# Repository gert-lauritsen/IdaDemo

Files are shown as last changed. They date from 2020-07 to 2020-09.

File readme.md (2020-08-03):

# Homeautomation fra pcb til produkt

## Beskrivelse

Vi vil forsøg på en aften at gå fra en ide til et produkt/prototype. Til formålet vil vi bruge Kicad, som vil blive gennemgået. Sende det til produktion monterer det og hælde kode i den. Til sidst vil vi lige se på WFF i homeautomation. Vi skal bl.a. se på dørlåse, automatiske gardiner og Automatisk lys.

* Kode på esp8266/esp32 i arduino IDE
* Udlægning af print med KIcad
* Mqtt og hvordan vi kan bruge det i automation
* Samarbejde via GitHUB

Niveauet bliver let så alle der har lyst til at prøve at udvikle deres egen print eller automatik, vil få en god start på deres produkt. Dette er for begynder, så bare kom og vær med.

Redskab bærbar med følgende installeret:
* [KiCad](https://kicad-pcb.org/download/)
* [Arduino](https://www.arduino.cc/)

Plan

* snakke om hvorfor og hvorfor ikke automation er smart
* Kicad gennemgang
* Kodning i arduino
* Samarbejde og deling via github

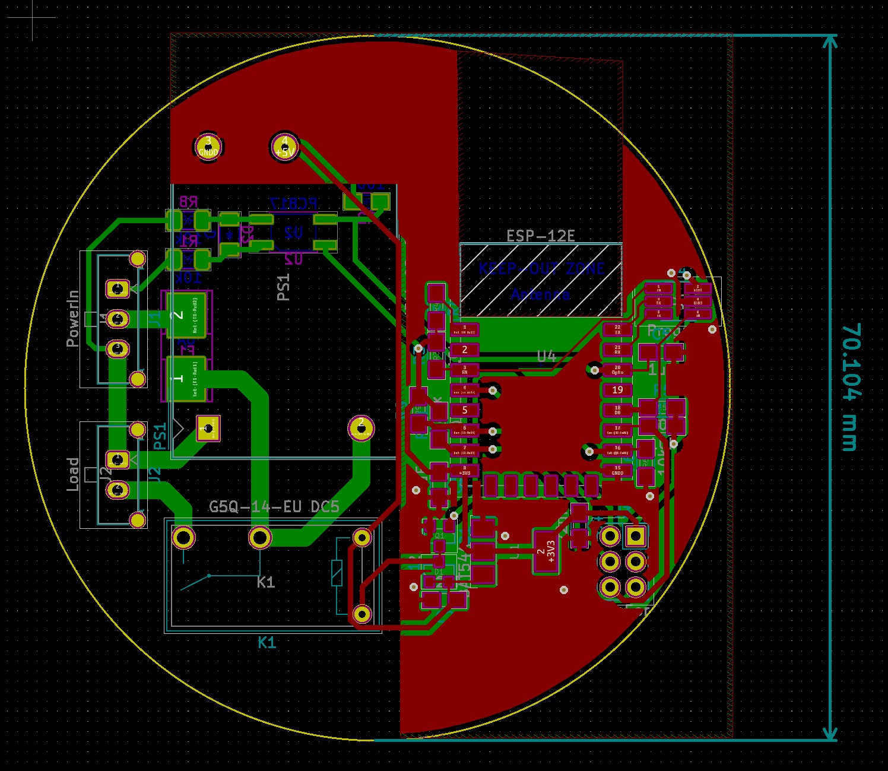
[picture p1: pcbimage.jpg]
Print


##Install ESP8266 på arduino
Under preference sætte følgede linie ind i additional boards:
https://dl.espressif.com/dl/package_esp32_index.json, http://arduino.esp8266.com/stable/package_esp8266com_index.json

Gå til Tools>Board>BoardManager søg efter esp8266 tryk install

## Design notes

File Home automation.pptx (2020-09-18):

## Home automation

Fra ide over pcb til prototype

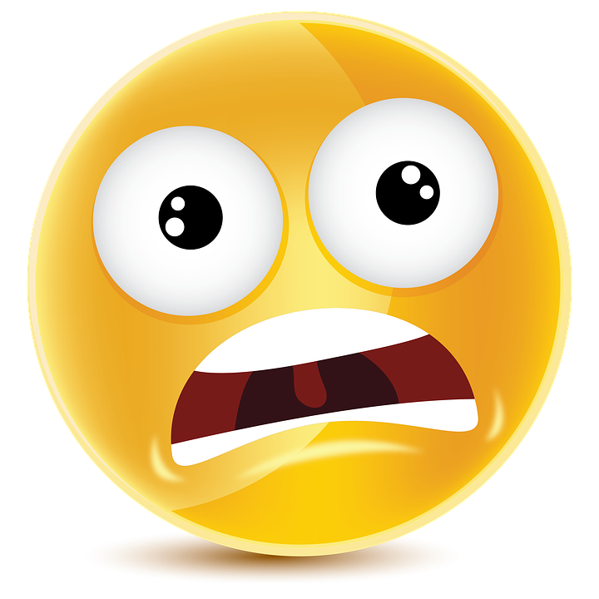
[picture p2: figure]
Smiley, Emoji, Følelser, Humørikon, Ansigt, Tegneserie

## Velkommen

- Esp8266 / Esp8265 / Esp32
- Wifi
- BootLoader
- Lysstyring (hvad Philips hue ikke kan)

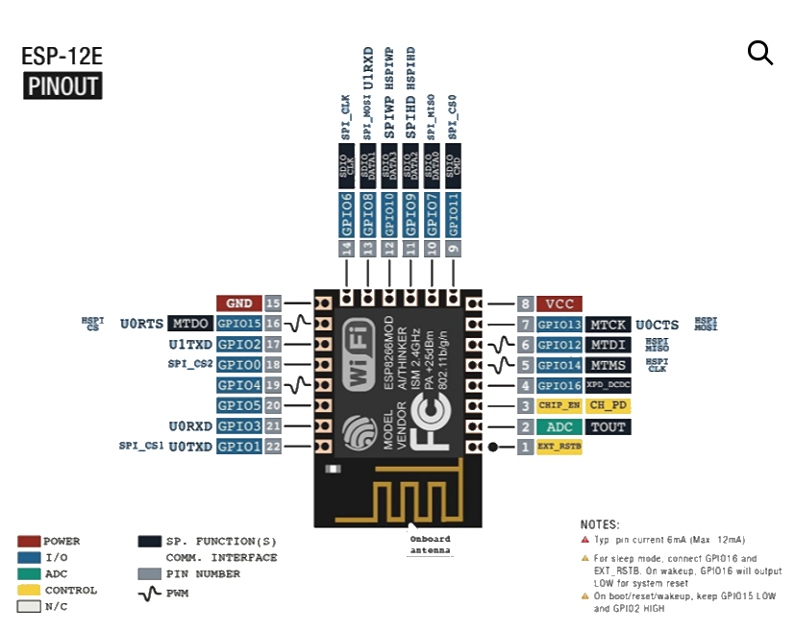
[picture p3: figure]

## Kicad

- Schematic (place, hieraki,
- SamacSys
- PCB
- Produktion

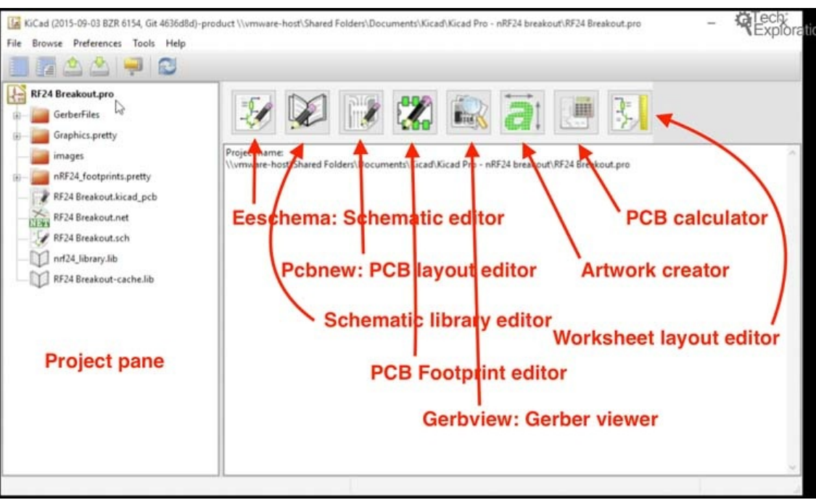
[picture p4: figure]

## GitHub

- Hvad er GIT
- Branches
- Samarbejde

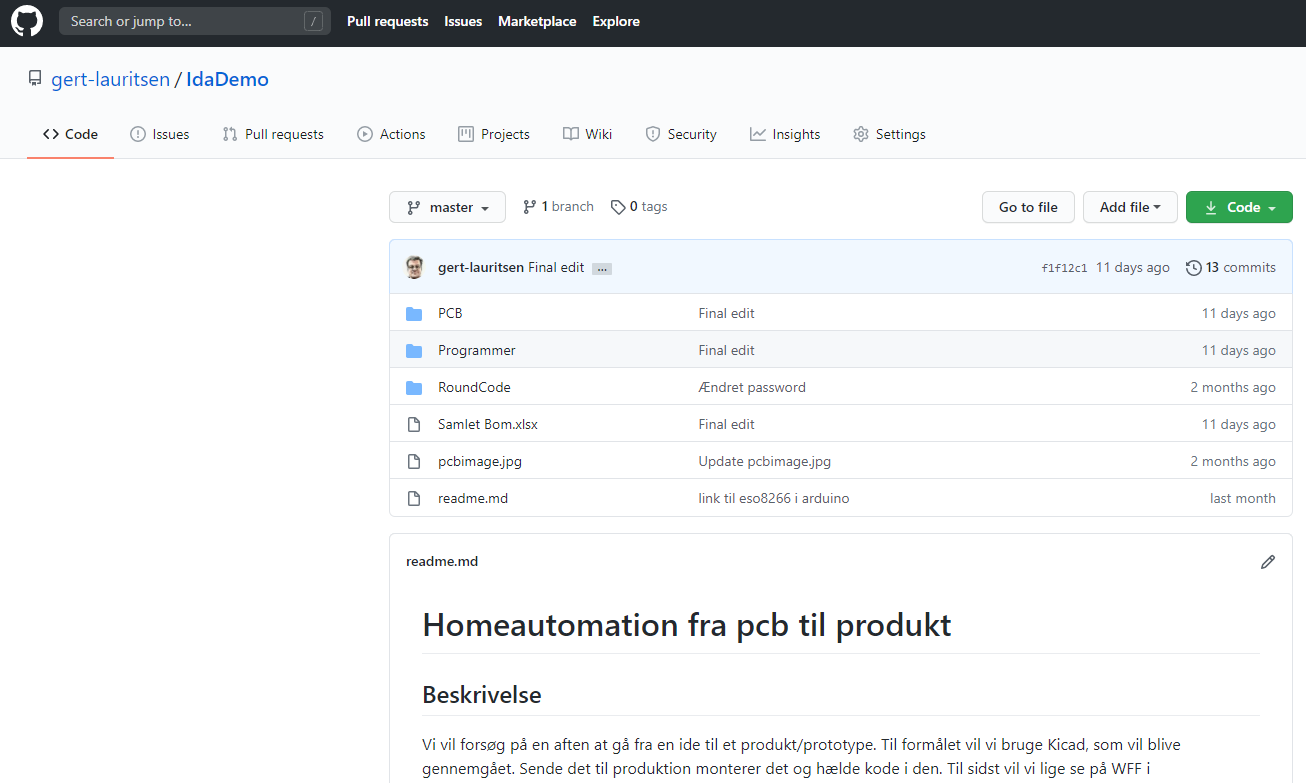
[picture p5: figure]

## MQTT

- Historik
- Pub/sub
- Frames, Topic, Json

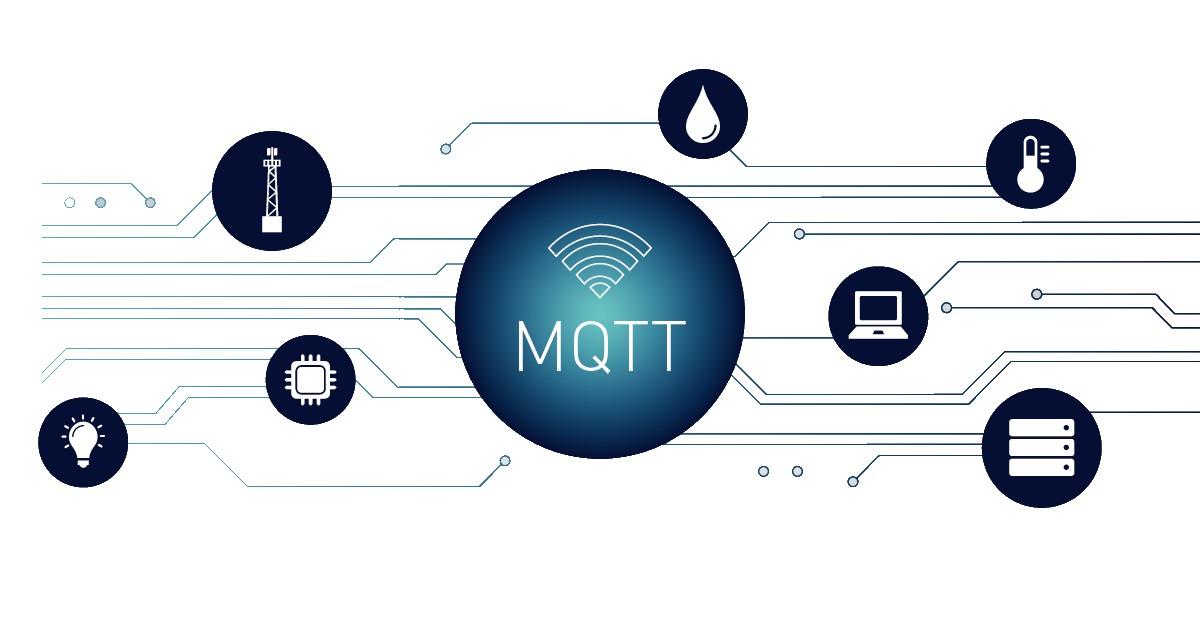
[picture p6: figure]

## OpenhaB

- Items
- Sitemap
- Rules

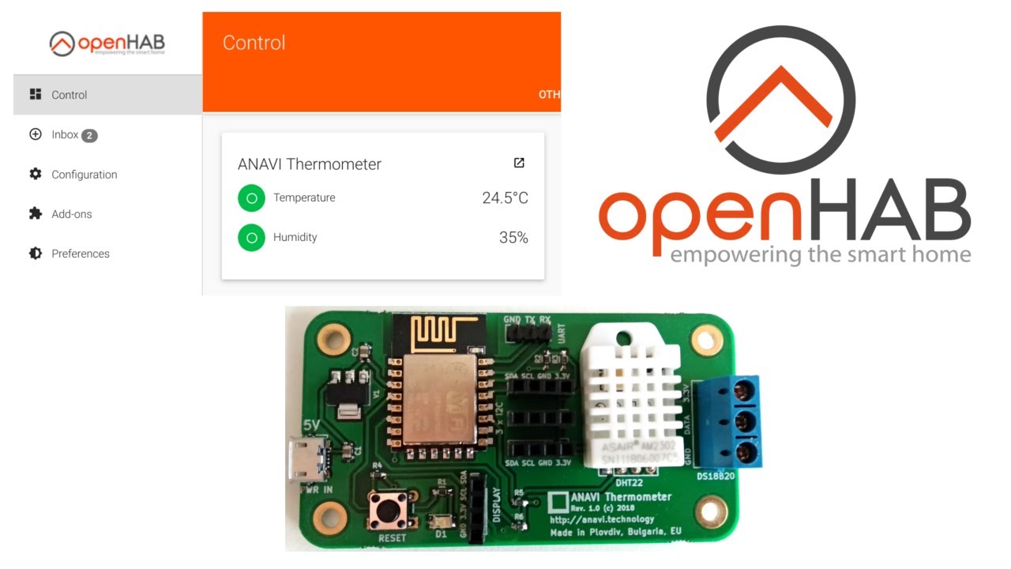
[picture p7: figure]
Connecting Temperature and Humidity Sensor DHT22 to OpenHAB 2 with MQTT - YouTube

## Arduino

- Install
- Libery
- Homeautomation “hallo world”

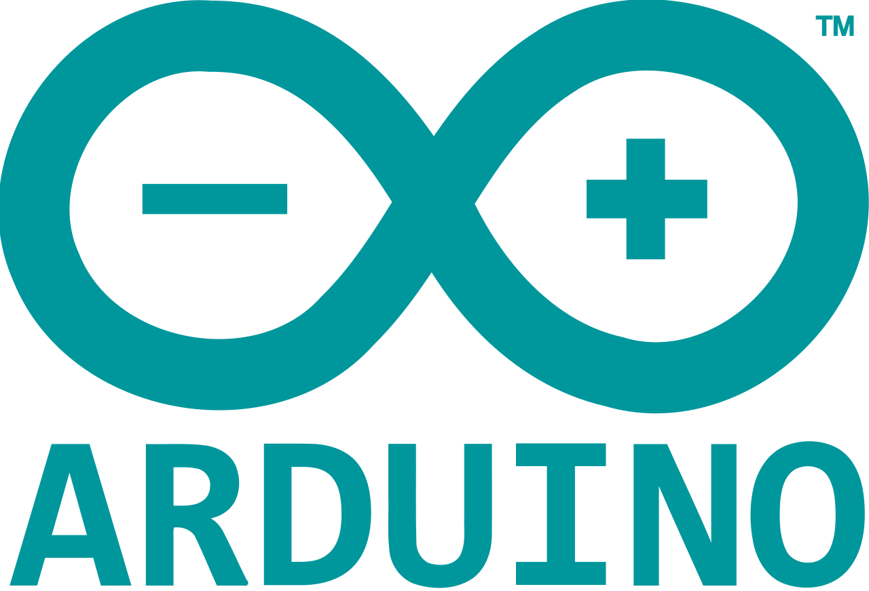
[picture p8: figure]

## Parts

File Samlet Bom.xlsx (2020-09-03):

U2 | FT232RL-REEL | Package_SO:SSOP-28_5.3x10.2mm_P0.65mm | https://www.ftdichip.com/Support/Documents/DataSheets/ICs/DS_FT232R.pdf | Active | Status | dk_Interface-Controllers | FT232RL-REEL | IC USB FS SERIAL UART 28-SSOP
J2 | Prog | Connector_PinHeader_1.27mm:PinHeader_2x03_P1.27mm_Vertical_SMD | ~ |  |  | Connector_Generic | Conn_02x03_Odd_Even | Generic connector, double row, 02x03, odd/even pin numbering scheme (row 1 odd numbers, row 2 even numbers), script generated (kicad-library-utils/schlib/autogen/connector/)
C4 | 100nF | Capacitor_SMD:C_0805_2012Metric | ~ |  |  | Device | C_Small | Unpolarized capacitor, small symbol
Q1 | BC846BS | Package_TO_SOT_SMD:SOT-363_SC-70-6 | https://assets.nexperia.com/documents/data-sheet/BC846BS.pdf |  |  | Transistor_BJT | BC846BS | 100mA IC, 65V Vce, Dual NPN/NPN Transistors, SOT-363
R5 | 10k | Resistor_SMD:R_0805_2012Metric | ~ |  |  | Device | R_Small | Resistor, small symbol
R6 | 10k | Resistor_SMD:R_0805_2012Metric | ~ |  |  | Device | R_Small | Resistor, small symbol
U1 | AP2112K-3.3 | Package_TO_SOT_SMD:SOT-23-5 | https://www.diodes.com/assets/Datasheets/AP2112.pdf |  |  | Regulator_Linear | AP2112K-3.3 | 600mA low dropout linear regulator, with enable pin, 3.8V-6V input voltage range, 3.3V fixed positive output, SOT-23-5
C2 | 1uF | Capacitor_SMD:C_0805_2012Metric | ~ |  |  | Device | C_Small | Unpolarized capacitor, small symbol
C3 | 1uF | Capacitor_SMD:C_0805_2012Metric | ~ |  |  | Device | C_Small | Unpolarized capacitor, small symbol
FB1 | Ferrite Bead | Inductor_SMD:L_0805_2012Metric | ~ |  |  | Device | Ferrite_Bead_Small | Ferrite bead, small symbol
C1 | 10nF | Capacitor_SMD:C_0805_2012Metric | ~ |  |  | Device | C_Small | Unpolarized capacitor, small symbol
D2 | LED | LED_SMD:LED_0805_2012Metric | ~ |  |  | Device | LED | Light emitting diode
D3 | LED | LED_SMD:LED_0805_2012Metric | ~ |  |  | Device | LED | Light emitting diode
R7 | 1k | Resistor_SMD:R_0805_2012Metric | ~ |  |  | Device | R_Small | Resistor, small symbol
R8 | 1k | Resistor_SMD:R_0805_2012Metric | ~ |  |  | Device | R_Small | Resistor, small symbol
SW1 | SW_Push | Button_Switch_SMD:SW_Push_1P1T_NO_6x6mm_H9.5mm | ~ |  |  | Switch | SW_Push | Push button switch, generic, two pins
SW2 | SW_Push | Button_Switch_SMD:SW_Push_1P1T_NO_6x6mm_H9.5mm | ~ |  |  | Switch | SW_Push | Push button switch, generic, two pins
J3 | USB_A | Connector_USB:USB_Mini-B_Wuerth_65100516121_Horizontal | ~ |  |  | Connector | USB_A | USB Type A connector
D1 | 82400102 | SOT95P280X145-6N | http://katalog.we-online.de/pbs/datasheet/82400102.pdf | 82400102 | Arrow Part Number | Programmer-rescue | 82400102-SamacSys_Parts
U2 | LTV-355T | Housings_SOIC:SO-4_4.4x3.6mm_Pitch2.54mm | https://www.mouser.dk/datasheet/2/239/LTV-355T%20Series-1308-1175436.pdf |  |  | Isolator | LTV-355T | Transistor Output Optocouplers Optocoupler Photodarlington
R1 | 33K | Resistor_SMD:R_1206_3216Metric | ~ |  |  | Device | R_Small | Resistor, small symbol
J1 | PowerIn | Connector_Molex:Molex_Micro-Fit_3.0_43650-0315_1x03_P3.00mm_Vertical | ~ |  |  | Connector_Generic | Conn_01x03 | Generic connector, single row, 01x03, script generated (kicad-library-utils/schlib/autogen/connector/)
J2 | Load | Connector_Molex:Molex_Micro-Fit_3.0_43650-0215_1x02_P3.00mm_Vertical | ~ |  |  | Connector_Generic | Conn_01x02 | Generic connector, single row, 01x02, script generated (kicad-library-utils/schlib/autogen/connector/)
U4 | ESP-12E | RF_Module:ESP-12E | http://wiki.ai-thinker.com/_media/esp8266/esp8266_series_modules_user_manual_v1.1.pdf |  |  | RF_Module | ESP-12E | 802.11 b/g/n Wi-Fi Module
R4 | 10k | Resistors_SMD:R_0805_HandSoldering | ~ |  |  | Device | R_Small | Resistor, small symbol
R3 | 10k | Resistors_SMD:R_0805_HandSoldering | ~ |  |  | Device | R_Small | Resistor, small symbol
R5 | 10k | Resistors_SMD:R_0805_HandSoldering | ~ |  |  | Device | R_Small | Resistor, small symbol
R6 | 10k | Resistors_SMD:R_0805_HandSoldering | ~ |  |  | Device | R_Small | Resistor, small symbol
R7 | 10k | Resistors_SMD:R_0805_HandSoldering | ~ |  |  | Device | R_Small | Resistor, small symbol
R2 | 100k | Resistors_SMD:R_0805_HandSoldering | ~ |  |  | Device | R_Small | Resistor, small symbol
Q1 | Sq2318AES | TO_SOT_Packages_SMD:SOT-23 | https://www.fairchildsemi.com/datasheets/2N/2N7002.pdf |  |  | Transistor_FET | 2N7002 | 0.115A Id, 60V Vds, N-Channel MOSFET, SOT-23
C2 | 1uF | Capacitors_SMD:C_0805_HandSoldering | ~ |  |  | Device | C_Small | Unpolarized capacitor, small symbol
C3 | 1uF | Capacitors_SMD:C_0805_HandSoldering | ~ |  |  | Device | C_Small | Unpolarized capacitor, small symbol
C4 | 1uF | Capacitors_SMD:C_0805_HandSoldering | ~ |  |  | Device | C_Small | Unpolarized capacitor, small symbol
D2 | D | Diodes_SMD:D_1206 | ~ |  |  | Device | D | Diode
K1 | G5Q-14-EU DC5 | Relay_THT:Relay_SPST_Omron-G5Q-1A | https://www.omron.com/ecb/products/pdf/en-g5q.pdf |  |  | Relay | G5Q-1A | Omron G5Q relay, Miniature Single Pole, SPST-NO, 10A
C5 | 1uF | Capacitors_SMD:C_0805_HandSoldering | ~ |  |  | Device | C_Small | Unpolarized capacitor, small symbol
PS1 | IRM-02-5 | Converter_ACDC:Converter_ACDC_MeanWell_IRM-02-xx_THT | http://www.meanwell.com/productPdf.aspx?i=675 |  |  | loftrelayRound-rescue | IRM-02-5-Converter_ACDC
J4 | Program | Pin_Headers:Pin_Header_Straight_2x03_Pitch1.27mm_SMD | ~ |  |  | Connector_Generic | Conn_02x03_Odd_Even | Generic connector, double row, 02x03, odd/even pin numbering scheme (row 1 odd numbers, row 2 even numbers), script generated (kicad-library-utils/schlib/autogen/connector/)
D1 | BAT54A | Package_TO_SOT_SMD:SOT-23 | http://www.diodes.com/_files/datasheets/ds11005.pdf |  |  | Diode | BAT54A | schottky barrier diode
F1 | 8A | SMD_Packages:Fuse_SMD | ~ |  |  | Device | Fuse | Fuse
J3 | SenSor | Socket_Strips:Socket_Strip_Straight_2x03_Pitch2.54mm | ~ |  |  | Connector_Generic | Conn_02x03_Counter_Clockwise | Generic connector, double row, 02x03, counter clockwise pin numbering scheme (similar to DIP packge numbering), script generated (kicad-library-utils/schlib/autogen/connector/)
R9 | 10k | Resistors_SMD:R_0805_HandSoldering | ~ |  |  | Device | R_Small | Resistor, small symbol
R10 | 10k | Resistors_SMD:R_0805_HandSoldering | ~ |  |  | Device | R_Small | Resistor, small symbol
R8 | 100k/400V/0,25W | Resistor_SMD:R_1206_3216Metric | ~ |  |  | Device | R_Small | Resistor, small symbol
U1 | AP2112K-3.3 | Package_TO_SOT_SMD:SOT-23-5 | https://www.diodes.com/assets/Datasheets/AP2112.pdf |  |  | Regulator_Linear | AP2112K-3.3 | 600mA low dropout linear regulator, with enable pin, 3.8V-6V input voltage range, 3.3V fixed positive output, SOT-23-5

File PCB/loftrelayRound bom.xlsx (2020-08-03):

Source: | C:\ArbejdsFile\Askob\IDA\IdaDemo\PCB\loftrelayRound.sch
Date: | 2020-03-08 10:44
Tool: | Eeschema (5.1.5)-3
Generator: | C:\Program Files\KiCad\bin\scripting\plugins/bom_csv_grouped_by_value_with_fp.py
Component Count: | 27
Ref | Qnty | Value | Cmp name | Footprint | Description | Vendor
C2,C3,C4 | 3 | 22uF | C_Small | Capacitors_SMD:C_0805_HandSoldering | Unpolarized capacitor, small symbol
C5 | 1 | 1uF | C_Small | Capacitors_SMD:C_0805_HandSoldering | Unpolarized capacitor, small symbol
D1 | 1 | BAT54A | BAT54A | Package_TO_SOT_SMD:SOT-23 | schottky barrier diode
D2 | 1 | SD1206S020S1R0 | SD1206S020S1R0 | Diodes_SMD:D_1206 | Diode
F1 | 1 | 8A | Fuse | SMD_Packages:Fuse_SMD | Fuse
J1 | 1 | PowerIn | Conn_01x03 | Connector_Molex:Molex_Micro-Fit_3.0_43650-0315_1x03_P3.00mm_Vertical | Generic connector, single row, 01x03, script generated (kicad-library-utils/schlib/autogen/connector/)
J2 | 1 | Load | Conn_01x02 | Connector_Molex:Molex_Micro-Fit_3.0_43650-0215_1x02_P3.00mm_Vertical | Generic connector, single row, 01x02, script generated (kicad-library-utils/schlib/autogen/connector/)
J3 | 1 | SenSor | Conn_02x03_Counter_Clockwise | Socket_Strips:Socket_Strip_Straight_2x03_Pitch2.54mm | Generic connector, double row, 02x03, counter clockwise pin numbering scheme (similar to DIP packge numbering), script generated (kicad-library-utils/schlib/autogen/connector/)
J4 | 1 | Program | Conn_02x03_Odd_Even | Pin_Headers:Pin_Header_Straight_2x03_Pitch1.27mm_SMD | Generic connector, double row, 02x03, odd/even pin numbering scheme (row 1 odd numbers, row 2 even numbers), script generated (kicad-library-utils/schlib/autogen/connector/)
K1 | 1 | G5Q-14-EU DC5 | G5Q-1A | Relays_THT:Relay_SPST_OMRON-G5Q | Omron G5Q relay, Miniature Single Pole, SPST-NO, 10A
PS1 | 1 | IRM-02-5 | IRM-02-5-Converter_ACDC | Converter_ACDC:Converter_ACDC_MeanWell_IRM-02-xx_THT
Q1 | 1 | Sq2318AES | Sq2318AES | TO_SOT_Packages_SMD:SOT-23 | 0.115A Id, 60V Vds, N-Channel MOSFET, SOT-23
R1,R8 | 2 | 33k | R_Small !!300V | Resistor_SMD:R_1206_3216Metric / Rated til 300V | Resistor, small symbol
R2 | 1 | 100k | R_Small | Resistors_SMD:R_0805_HandSoldering | Resistor, small symbol
R3,R4,R5,R6,R7,R9,R10 | 7 | 10k | R_Small | Resistors_SMD:R_0805_HandSoldering | Resistor, small symbol
U1 | 1 | AP1117-33 | AP1117-33 | Package_TO_SOT_SMD:SOT-223-3_TabPin2 | 1A Low Dropout regulator, positive, 3.3V fixed output, SOT-223
U2 | 1 | PC817 | PC817 | Housings_SOIC:SO-4_4.4x3.6mm_Pitch2.54mm | DC Optocoupler, Vce 35V, CTR 50-300%, DIP-4
U4 | 1 | ESP-12E | ESP-12E | RF_Module:ESP-12E | 802.11 b/g/n Wi-Fi Module

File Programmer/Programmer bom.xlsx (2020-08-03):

Source:, | Z:\Gert.lauritsen\Arbejdsfiler\Askob\FritidsProjekter\HomeAutomation\IdaDemo\Programmer\Programmer.sch
Date:, | 2020-08-03 18:00
Tool:, | Eeschema (5.1.6)-1
Generator:, | C:\Program Files\KiCad\bin\scripting\plugins/bom_csv_grouped_by_value_with_fp.py
Component Count:, | 17
Ref, | Qnty | Value | Cmp name | Footprint | Description | Vendor
C1, , | 1 | 10nF | C_Small | Capacitor_SMD:C_0805_2012Metric | Unpolarized capacitor, small symbol
C2, C3, , | 2 | 1uF | C_Small | Capacitor_SMD:C_0805_2012Metric | Unpolarized capacitor, small symbol
C4, , | 1 | 100nF | C_Small | Capacitor_SMD:C_0805_2012Metric | Unpolarized capacitor, small symbol
D1, , | 1 | 824014 | USBLC6-2SC6 | Package_TO_SOT_SMD:SOT-23-6 | TVS DIODE 5.25V 17V SOT23-6
FB1, , | 1 | Ferrite Bead | Ferrite_Bead_Small | Inductor_SMD:L_0805_2012Metric | Ferrite bead, small symbol
J1, , | 1 | USB_C_Receptacle_USB2.0 | USB_C_Receptacle_USB2.0 | Connector_USB:USB_C_Receptacle_Amphenol_12401548E4-2A | USB 2.0-only Type-C Receptacle connector
J2, , | 1 | Prog | Conn_02x03_Odd_Even | Connector_PinHeader_1.27mm:PinHeader_2x03_P1.27mm_Vertical_SMD | Generic connector, double row, 02x03, odd/even pin numbering scheme (row 1 odd numbers, row 2 even numbers), script generated (kicad-library-utils/schlib/autogen/connector/)
Q1, , | 1 | BC846BS | BC846BS | Package_TO_SOT_SMD:SOT-363_SC-70-6 | 100mA IC, 65V Vce, Dual NPN/NPN Transistors, SOT-363
R1, R2, R3, R4, , | 4 | 5k1 | R_Small | Resistor_SMD:R_0805_2012Metric | Resistor, small symbol
R5, R6, , | 2 | 10k | R_Small | Resistor_SMD:R_0805_2012Metric | Resistor, small symbol
U1, , | 1 | AP2112K-3.3 | AP2112K-3.3 | Package_TO_SOT_SMD:SOT-23-5 | 600mA low dropout linear regulator, with enable pin, 3.8V-6V input voltage range, 3.3V fixed positive output, SOT-23-5
U2, , | 1 | FT232RL-REEL | FT232RL-REEL | Package_SO:SSOP-28_5.3x10.2mm_P0.65mm | IC USB FS SERIAL UART 28-SSOP

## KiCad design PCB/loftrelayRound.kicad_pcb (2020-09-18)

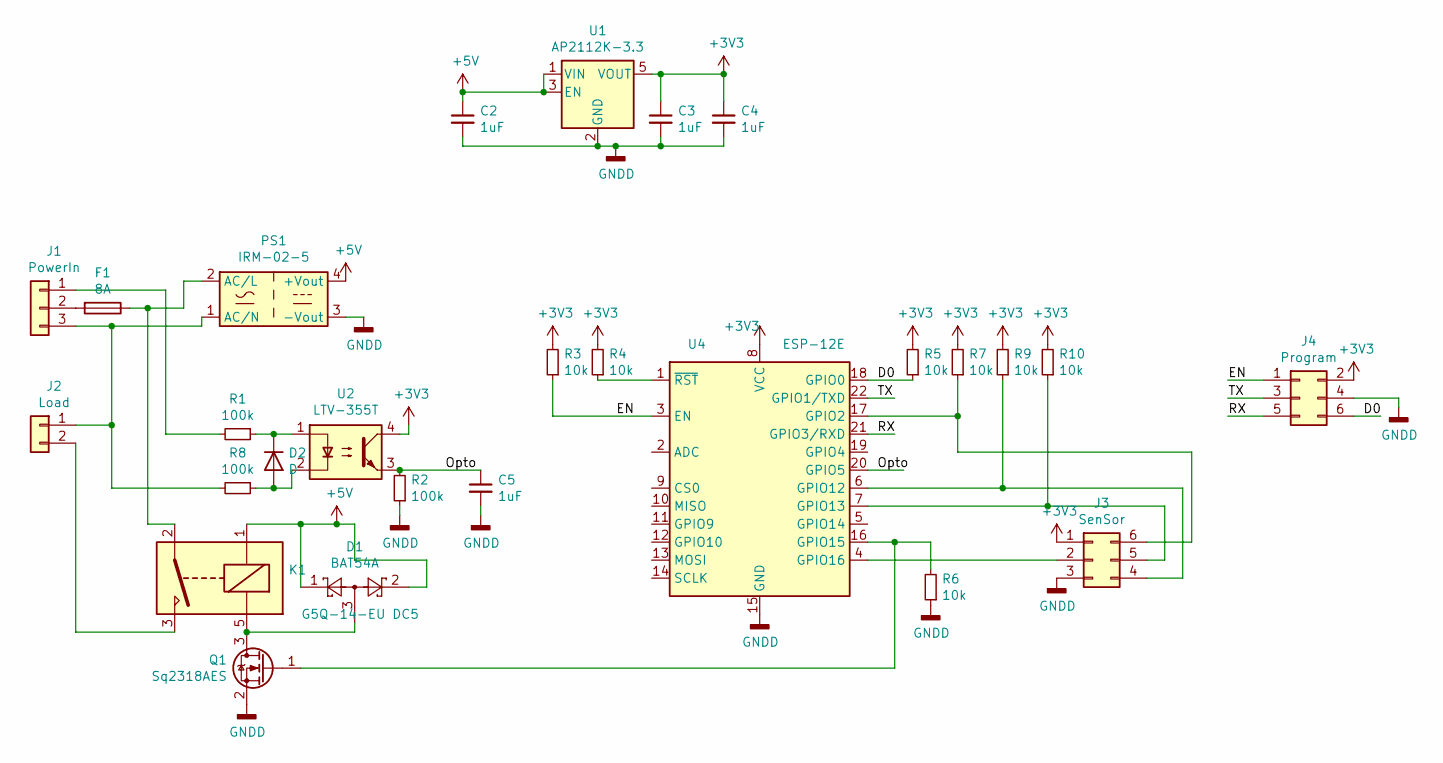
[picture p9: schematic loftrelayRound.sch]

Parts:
C2, C3, C4, C5: 1uF; C_0805_HandSoldering
D1: BAT54A; SOT-23
D2: D; D_1206
F1: 8A; Fuse_SMD
J1: PowerIn; Molex_Micro-Fit_3.0_43650-0315_1x03_P3.00mm_Vertical
J2: Load; Molex_Micro-Fit_3.0_43650-0215_1x02_P3.00mm_Vertical
J3: SenSor; Socket_Strip_Straight_2x03_Pitch2.54mm
J4: Program; Pin_Header_Straight_2x03_Pitch1.27mm_SMD
K1: G5Q-14-EU DC5; Relay_SPST_Omron-G5Q-1A
PS1: IRM-02-5; Converter_ACDC_MeanWell_IRM-02-xx_THT
Q1: Sq2318AES; SOT-23
R1, R8: 100k; R_1206_3216Metric
R2: 100k; R_0805_HandSoldering
R3, R4, R5, R6, R7, R9, R10: 10k; R_0805_HandSoldering
U1: AP2112K-3.3; SOT-23-5
U2: LTV-355T; SO-4_4.4x3.6mm_Pitch2.54mm
U4: ESP-12E

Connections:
+3V3: C3.1, C4.1, J3.1, J4.2, R3.2, R4.2, R5.2, R7.2, R9.2, R10.2, U1.5 (VOUT), U2.4, U4.8 (VCC)
+5V: C2.1, D1.1, D1.2, K1.1, PS1.4 (+Vout), U1.1 (VIN), U1.3 (EN)
/D0: J4.6, R5.1, U4.18 (GPIO0)
/EN: J4.1, R3.1, U4.3 (EN)
/Opto: C5.1, R2.2, U2.3, U4.20 (GPIO5)
/RX: J4.5, U4.21 (GPIO3/RXD)
/TX: J4.3, U4.22 (GPIO1/TXD)
GNDD: C2.2, C3.2, C4.2, C5.2, J3.3, J4.4, PS1.3 (-Vout), Q1.2 (S), R2.1, R6.1, U1.2 (GND), U4.15 (GND)
unnamed: D1.3, K1.5, Q1.3 (D)
unnamed: D2.1 (K), R1.1, U2.1
unnamed: D2.2 (A), R8.1, U2.2
unnamed: F1.1, K1.2, PS1.2 (AC/L)
unnamed: F1.2, J1.2
unnamed: J1.1, R1.2
unnamed: J1.3, J2.1, PS1.1 (AC/N), R8.2
unnamed: J2.2, K1.3
unnamed: J3.2, U4.4 (GPIO16)
unnamed: J3.4, R9.1, U4.6 (GPIO12)
unnamed: J3.5, R10.1, U4.7 (GPIO13)
unnamed: J3.6, R7.1, U4.17 (GPIO2)
unnamed: Q1.1 (G), R6.2, U4.16 (GPIO15)
unnamed: R4.1, U4.1 (~RST)

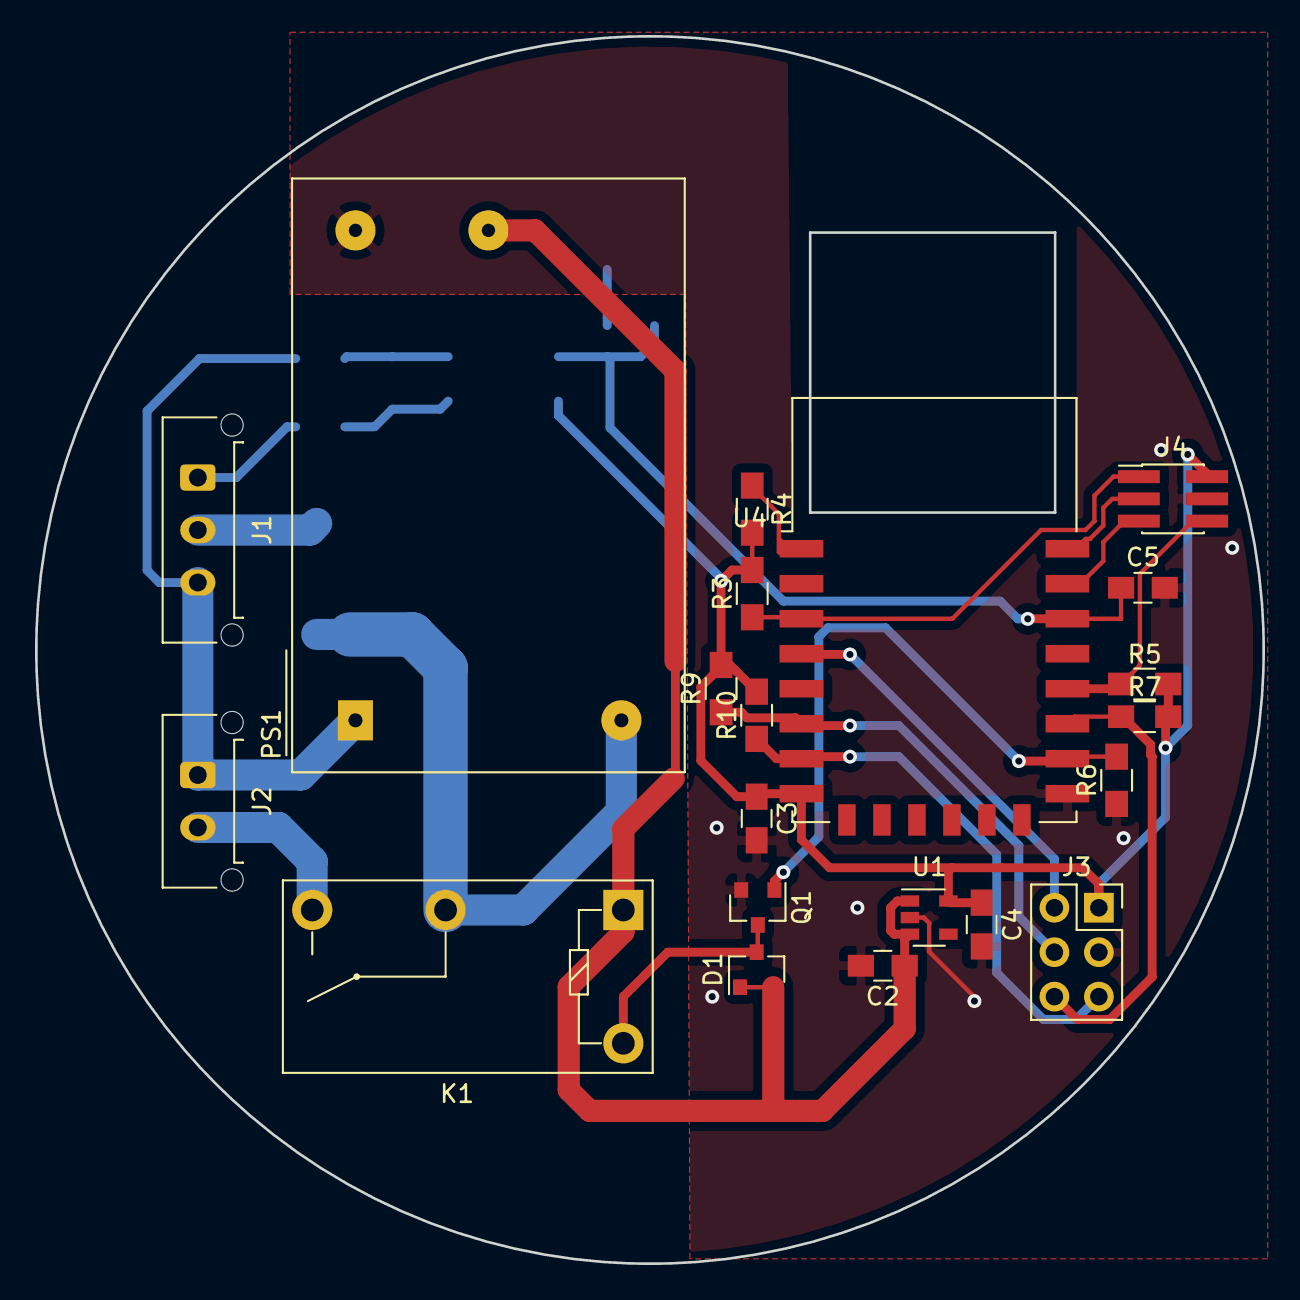
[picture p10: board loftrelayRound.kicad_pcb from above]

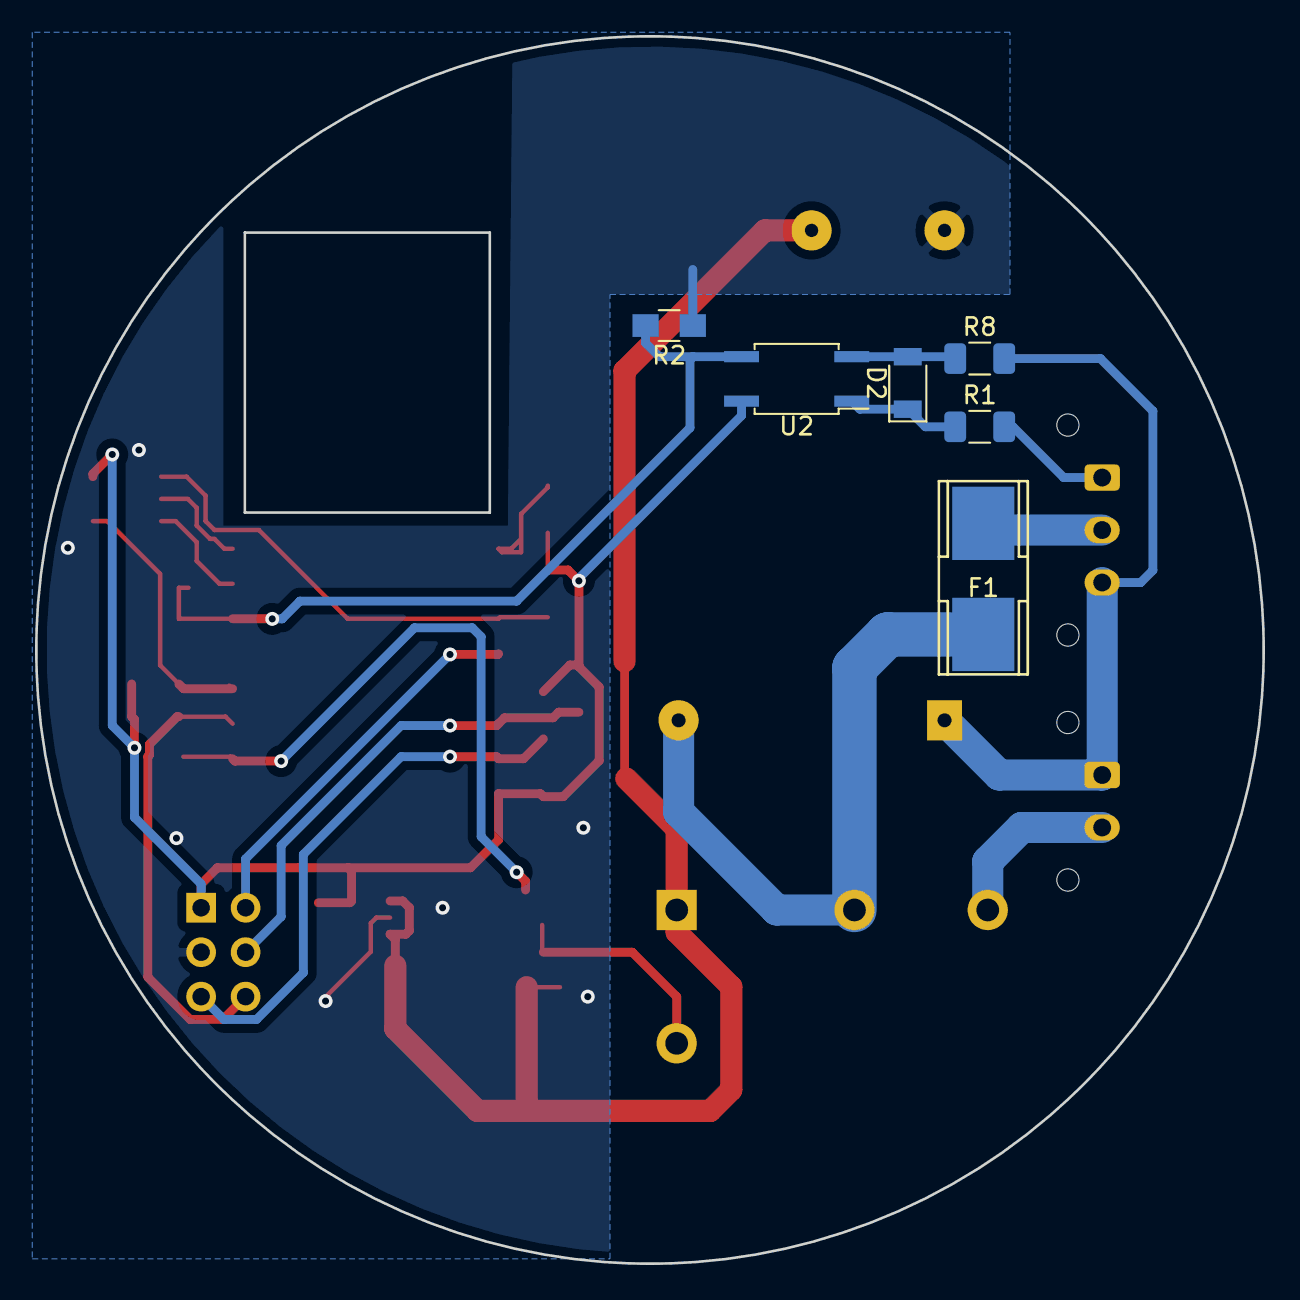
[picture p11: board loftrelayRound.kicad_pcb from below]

Board: 2 copper layers, 70.1 x 70.1 mm, 27 parts (6 on the bottom side), 22 nets.

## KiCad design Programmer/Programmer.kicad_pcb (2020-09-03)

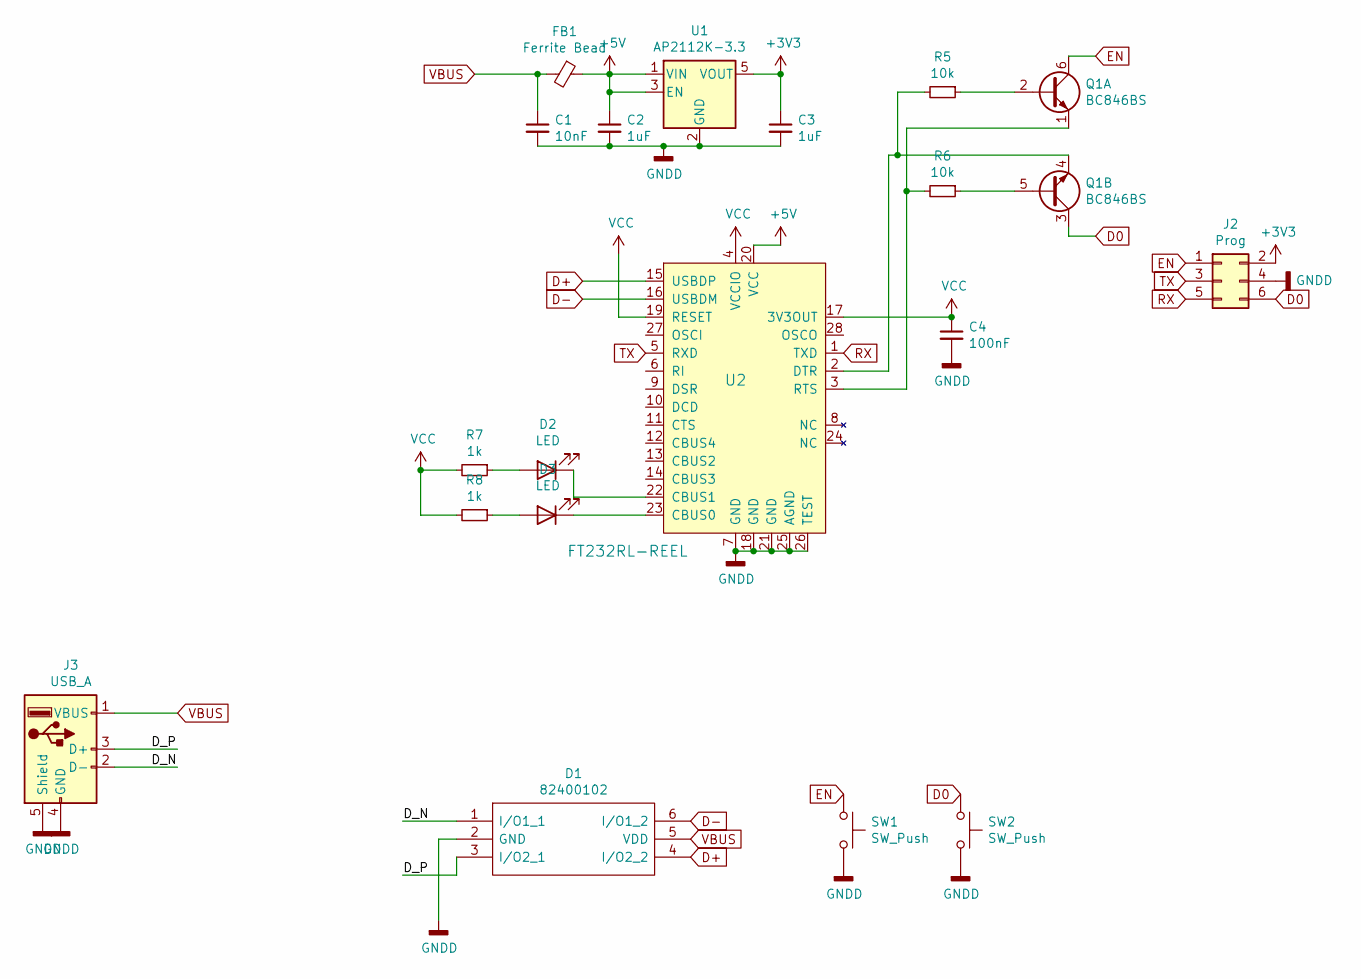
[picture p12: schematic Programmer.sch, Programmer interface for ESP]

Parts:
C1: 10nF; C_0805_2012Metric
C2, C3: 1uF; C_0805_2012Metric
C4: 100nF; C_0805_2012Metric
D1: 82400102; SOT95P280X145-6N; Manufacturer_Part_Number 82400102; Mouser Part Number 710-82400102
D2, D3: LED; LED_0805_2012Metric
FB1: Ferrite Bead; L_0805_2012Metric
J2: Prog; PinHeader_2x03_P1.27mm_Vertical_SMD
J3: USB_A; USB_Mini-B_Wuerth_65100516121_Horizontal
Q1: BC846BS; SOT-363_SC-70-6
R5, R6: 10k; R_0805_2012Metric
R7, R8: 1k; R_0805_2012Metric
SW1, SW2: SW_Push; SW_Push_1P1T_NO_6x6mm_H9.5mm
U1: AP2112K-3.3; SOT-23-5
U2: FT232RL-REEL; SSOP-28_5.3x10.2mm_P0.65mm; MPN FT232RL-REEL; Digi-Key_PN 768-1007-1-ND

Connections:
+3V3: C3.1, J2.2, U1.5 (VOUT)
+5V: C2.1, FB1.1, U1.1 (VIN), U1.3 (EN), U2.20 (VCC)
/D_N: D1.1 (I/O1_1), J3.2 (D-)
/D_P: D1.3 (I/O2_1), J3.3 (D+)
D0: J2.6, Q1.3 (C2), SW2.1
D+: D1.4 (I/O2_2), U2.15 (USBDP)
D-: D1.6 (I/O1_2), U2.16 (USBDM)
EN: J2.1, Q1.6 (C1), SW1.1
GNDD: C1.2, C2.2, C3.2, C4.2, D1.2 (GND), J2.4, J3.4 (GND), J3.5 (Shield), SW1.2, SW2.2, U1.2 (GND), U2.7 (GND), U2.18 (GND), U2.21 (GND), U2.25 (AGND), U2.26 (TEST)
unnamed: D2.1 (K), U2.22 (CBUS1)
unnamed: D2.2 (A), R7.1
unnamed: D3.1 (K), U2.23 (CBUS0)
unnamed: D3.2 (A), R8.1
unnamed: Q1.1 (E1), R6.2, U2.3 (RTS)
unnamed: Q1.2 (B1), R5.1
unnamed: Q1.4 (E2), R5.2, U2.2 (DTR)
unnamed: Q1.5 (B2), R6.1
RX: J2.5, U2.1 (TXD)
TX: J2.3, U2.5 (RXD)
VBUS: C1.1, D1.5 (VDD), FB1.2, J3.1 (VBUS)
VCC: C4.1, R7.2, R8.2, U2.4 (VCCIO), U2.17 (3V3OUT), U2.19 (RESET)

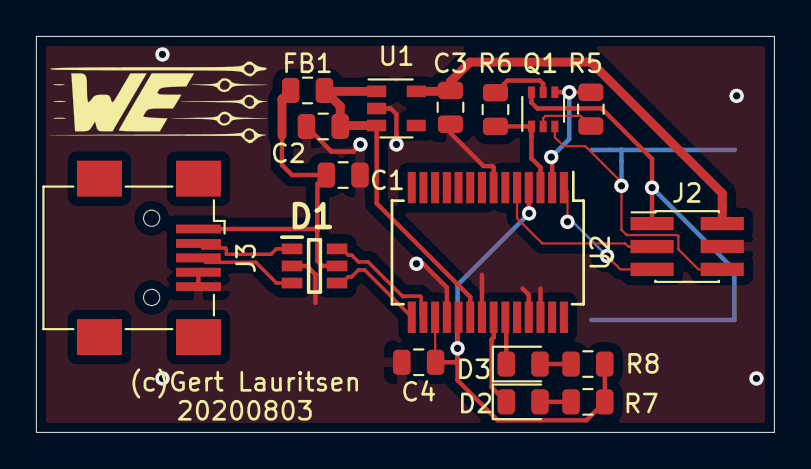
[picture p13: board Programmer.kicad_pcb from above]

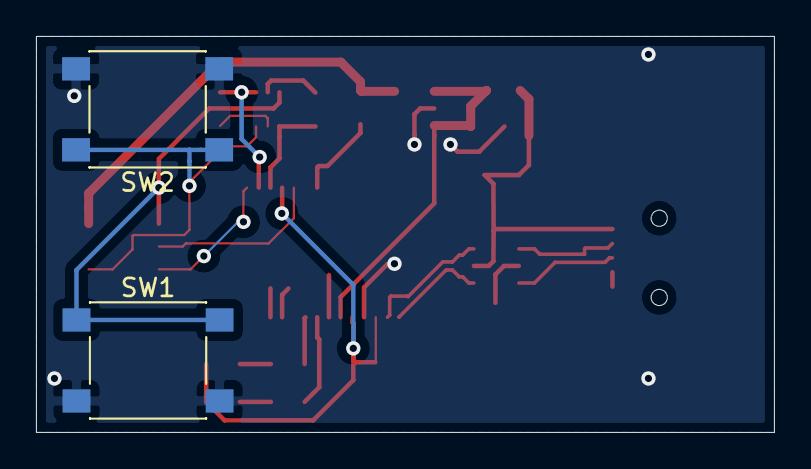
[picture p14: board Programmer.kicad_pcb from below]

Board: 2 copper layers, 41.0 x 22.0 mm, 19 parts (2 on the bottom side), 21 nets.

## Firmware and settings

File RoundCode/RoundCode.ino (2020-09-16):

#include <FS.h>                   //this needs to be first, or it all crashes and burns...
#include <ESP8266WiFi.h>
#include <ESP8266mDNS.h>
#include <WiFiUdp.h>
#include <ArduinoOTA.h>
#include <String.h>
#include <PubSubClient.h>
#include <DNSServer.h>            //Local DNS Server used for redirecting all requests to the configuration portal
#include <ESP8266WebServer.h>     //Local WebServer used to serve the configuration portal
#include <ArduinoJson.h>          //https://github.com/bblanchon/ArduinoJson
#include "password.h"

const int relay     = 15;
const int OptoInput = 5;

char ID[8];
char mqttTopicStatus[25];
char ONOFF_FEED[25];

bool CmdOnOff = false; //input state om den er og eller off (optokobler)
bool LastCmdOnOff = false; // for at kunne toggle på ændringer
long Cmdonofftimeout = 0; //
char IPadr[20];

WiFiClient wificlient;
PubSubClient client(wificlient);

int updatestatus = 0;
//flag for saving data
bool shouldSaveConfig = false;
char msg[25];
bool AcOnOff;
long lasttest;
//---------------------------------------------------------------------------------------------------------

void switchPressed ()
{
  static unsigned long LastKeypress;
  if ((LastKeypress == 0) | ((millis() - LastKeypress) > 200)) {
    CmdOnOff=!CmdOnOff;
    digitalWrite(relay,CmdOnOff);
    updatestatus = 1;
    LastKeypress = millis();
  }
}

// Message received through MQTT
void callback(char* topic, byte* payload, unsigned int length) {
  Serial.print(topic);
  Serial.print(" Message arrived ");
  if (payload[0] == '1') CmdOnOff=1;
  if (payload[0] == '0') CmdOnOff=0;
  if (payload[0] == 'T') CmdOnOff=!CmdOnOff;  
   digitalWrite(relay,CmdOnOff);
   updatestatus = 1;
}





void setup() {
  sprintf(&ID[0], "%08X", ESP.getChipId());
  Serial.begin(115200);
  Serial.println("");
  //clean FS, for testing
  //SPIFFS.format();

  wifiSetup();

  Serial.println("Ready");
  Serial.print("IP address: ");
  Serial.println(WiFi.localIP());

  pinMode(relay, OUTPUT);
  digitalWrite(relay, LOW);
  digitalWrite (OptoInput, HIGH); // internal pull-up resistor  
  Serial.print(ID);
  Serial.println(" Booting");
  Serial.println("Setup Done");
  updatestatus = 1; //Start med at sende status til senver
}

void SendStatus() {
  char msg[80];
  char temp[25];
  DynamicJsonBuffer jsonBuffer;
  JsonObject& json = jsonBuffer.createObject();
  if (CmdOnOff) json["state"]="ON"; else json["state"]="OFF";
  json["RSSI"]=WiFi.RSSI();
  json["IP"]=IPadr;
  json.printTo(Serial);
  Serial.println("");
  json.printTo(msg);
  client.publish(mqttTopicStatus, msg);
}

void loop() {
  // put your main code here, to run repeatedly:
  wifiHandle();
  if (millis()>lasttest) {
     AcOnOff=digitalRead(OptoInput); //læser state
     lasttest=millis()+500;
  }   
  if (AcOnOff != LastCmdOnOff) {
    //Toggle output
    LastCmdOnOff = AcOnOff;
    CmdOnOff=!CmdOnOff;
    digitalWrite(relay,CmdOnOff);
    updatestatus = 1;
  }
  if (updatestatus) {
    updatestatus = 0;
    SendStatus();
  }
}

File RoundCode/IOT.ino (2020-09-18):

void ReadSetup() {
  Serial.println("mounted file system");
  if (SPIFFS.exists("/config.json")) {
    //file exists, reading and loading
    Serial.println("reading config file");
    File configFile = SPIFFS.open("/config.json", "r");
    if (configFile) {
      Serial.println("opened config file");
      size_t size = configFile.size();
      // Allocate a buffer to store contents of the file.
      std::unique_ptr<char[]> buf(new char[size]);

      configFile.readBytes(buf.get(), size);
      DynamicJsonBuffer jsonBuffer;
      JsonObject& json = jsonBuffer.parseObject(buf.get());
      //json.printTo(Serial);
      if (json.success()) {
        Serial.println("\nparsed json");

        strcpy(mqtt_server, json["mqtt_server"]);
        strcpy(mqtt_port, json["mqtt_port"]);
        strcpy(username, json["username"]);
        strcpy(password, json["password"]);
        strcpy(ssid, json["ssid"]);
        strcpy(wifipassword, json["wifipassword"]);
      } else {
        Serial.println("failed to load json config");
      }
    }
  }
}

void SaveConfig() {
  Serial.println("saving config");
  DynamicJsonBuffer jsonBuffer;
  JsonObject& json = jsonBuffer.createObject();
  json["mqtt_server"] = mqtt_server;
  json["mqtt_port"] = mqtt_port;
  json["username"] = username;
  json["password"] = password;
  json["ssid"] = ssid;
  json["wifipassword"] = wifipassword;

  File configFile = SPIFFS.open("/config.json", "w");
  if (!configFile) {
    Serial.println("failed to open config file for writing");
  }

  json.printTo(Serial);
  json.printTo(configFile);
  configFile.close();
  //end save
}

void wifiSetup() {
  WiFi.mode(WIFI_STA);
  WiFi.hostname(ID);
  sprintf(mqttTopicStatus, "/%08X/Status", ESP.getChipId());
  sprintf(ONOFF_FEED, "/%08X/cmd", ESP.getChipId());

  if (SPIFFS.begin()) 
   if (SPIFFS.exists("/config.json")) ReadSetup(); else SaveConfig();
   
  WiFi.mode(WIFI_STA);
  WiFi.begin(&ssid[0], &wifipassword[0]);
  WiFi.hostname(ID);


  //if you get here you have connected to the WiFi
  if (WiFi.waitForConnectResult() == WL_CONNECTED)
    Serial.println("connected...yeey :)");
  else {
    Serial.println("Connection Failed! Rebooting...");
    delay(5000);
    ESP.restart();
  }

  Serial.println("Proceeding");
  Serial.printf(" ESP8266 Chip id = -%08X-\n", ESP.getChipId());


  // Port defaults to 8266
  // ArduinoOTA.setPort(8266);

  // Hostname defaults to esp8266-[ChipID]
  ArduinoOTA.setHostname(ID);

  // No authentication by default
  // ArduinoOTA.setPassword((const char *)"123");

  ArduinoOTA.onStart([]() {
    Serial.println("Start");
  });
  ArduinoOTA.onEnd([]() {
    Serial.println("\nEnd");
  });
  ArduinoOTA.onProgress([](unsigned int progress, unsigned int total) {
    Serial.printf("Progress: %u%%\r", (progress / (total / 100)));
  });
  ArduinoOTA.onError([](ota_error_t error) {
    Serial.printf("Error[%u]: ", error);
    if      (error == OTA_AUTH_ERROR   ) Serial.println("Auth Failed");
    else if (error == OTA_BEGIN_ERROR  ) Serial.println("Begin Failed");
    else if (error == OTA_CONNECT_ERROR) Serial.println("Connect Failed");
    else if (error == OTA_RECEIVE_ERROR) Serial.println("Receive Failed");
    else if (error == OTA_END_ERROR    ) Serial.println("End Failed");
  });
  ArduinoOTA.begin();

  /* Prepare MQTT client */
//  Serial.printf("MQTTServer %s port %s\n", mqtt_server, mqtt_port);
  client.setServer(mqtt_server, atoi(mqtt_port));
  client.setCallback(callback);

}


String ipToString(IPAddress ip) {
  String s = "";
  for (int i = 0; i < 4; i++)
    s += i  ? "." + String(ip[i]) : String(ip[i]);
  return s;
}

void reconnect() {
  // Loop until we're reconnected
  char str[25];
  while (!client.connected()) {
    Serial.print("Attempting MQTT connection...");
    // Attempt to connect
    if (client.connect(ID)) {
      Serial.println("connected");
      client.subscribe(ONOFF_FEED);
      ipToString(WiFi.localIP()).toCharArray(IPadr, 25);
    } else {
      Serial.print("failed, rc=");
      Serial.print(client.state());
      Serial.println(" try again in 5 seconds");
      // Wait 5 seconds before retrying
      delay(5000);
    }
  }
}

void wifiHandle() {
  ArduinoOTA.handle();
  if (WiFi.status() == WL_CONNECTED) {
    if (!client.connected()) reconnect(); else client.loop();
  }
}

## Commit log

2020-07-29 Ændret stik
    Har ændret til til 3mm mikrofit fjernet C ved optocobler for at undgå stød.
    [loftrelayRound-B_Cu.gbr, loftrelayRound-B_Mask.gbr, loftrelayRound-B_Paste.gbr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]
2020-08-03 Update af komponeter samt ny programmer
    [Programmer bom.xlsx, Programmer.kicad_pcb, Programmer.sch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]
2020-08-03 Rettelse på programmer vcc
    [Programmer-B_Cu.gbr, Programmer-B_Mask.gbr, Programmer-B_Paste.gbr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]
2020-08-03 Ændret track,
    således at vi ved 5A får en max temperatur forøgelse på 10°C
    [loftrelayRound-B_Cu.gbr, loftrelayRound-B_Mask.gbr, loftrelayRound-B_Paste.gbr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]
2020-08-03 link til eso8266 i arduino
2020-08-04 knap tilføjet
    [Programmer-B_Cu.gbr, Programmer-B_Mask.gbr, Programmer-B_Paste.gbr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]
2020-08-05 3d footprint
    [loftrelayRound.kicad_pcb, loftrelayRound.sch]
2020-09-03 Final edit
    Ændret LDO , da jeg ikke kunne skaffe den anden på mouser kun i kina, hvilket jeg ikke har tid til. Rettet en bane der kom lidt for tæt og fejlede i første forsøg
    [Programmer-B_Cu.gbr, Programmer-B_Mask.gbr, Programmer-B_Paste.gbr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]
2020-09-18 Update referance
    [loftrelayRound.kicad_pcb]
2020-09-18 Tilføjet powerpoint
